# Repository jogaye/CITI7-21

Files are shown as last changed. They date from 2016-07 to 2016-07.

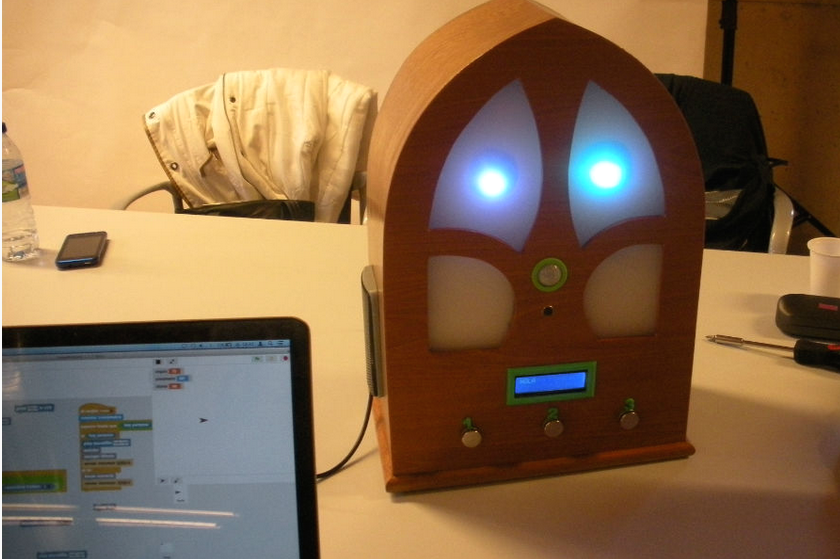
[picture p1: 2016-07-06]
Citi7-21.png

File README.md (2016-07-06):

# Citi7-21
Robot Nous Artesans

Projecte dels Nous Artesans del Citilab de Cornellà
A project of Citilab Cornellà New Artesans
http://nartesanos.citilab.eu/

Amb el suport del equip Edutec del Citilab 
With the support of Edutec Citilab team
http://edutec.citilab.eu

Robot que grava amb una tarja SD els suggeriments dels usuaris del Citilab  i que crida l'atenció per fomentar la participació.

Parla en 3 idiomes, es mou, té un sensor de presència, un display LCD, ulls amb LEDS RGB motoritzats i botons capacitius.

Està construït amb un Arduino Mega i programat amb Snap4Arduino. S'ha ampliat el Firmata per poder incorporar tots aquests elements al Snap4Arduino.

The Robot records in aSD card the feedback form Citilab users and draws his attention to encourage participation.

It speaks three languages, moves, has a presence sensor, a LCD display, two  RGBs LED motorized eyes and capacitive buttons.

It is built with an Arduino Mega and programmed with Snap4Arduino. Firmata has been expanded to incorporate all these elements to Snap4Arduino.

![Hello, I'm Citi7-21] (https://github.com/jogaye/Citi7-21/blob/master/Citi7-21.jpg)

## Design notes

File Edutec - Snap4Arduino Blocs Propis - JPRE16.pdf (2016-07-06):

### Edutec - Citilab

### Blocs propis amb Snap4Arduino

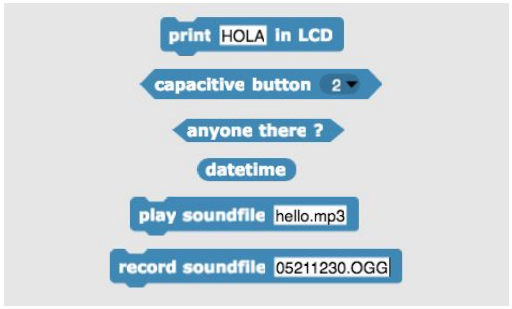
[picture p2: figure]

### Citilab Cornellà, 21 de maig 2016

Víctor Casado
José García
Joan Güell

# >> Citi 7 21

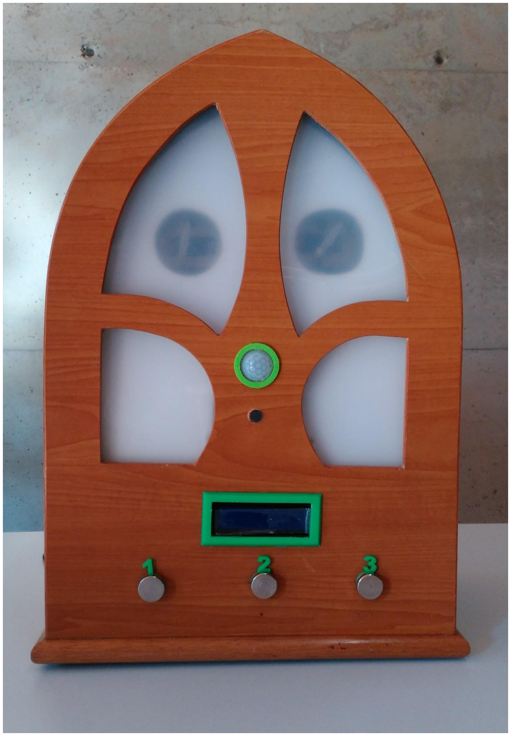
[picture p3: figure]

❏ | Robot en forma de “radio capilla” amb l’objectiu de gravar els suggeriments, propostes i també queixes dels usuaris del Citilab.
❏ | Parla en 3 idiomes, es mou, té un sensor de presència, un display LCD, ulls amb LEDS RGB motoritzats i botons capacitius.
❏ | Programat en Snap4Arduino

# >> Nous Artesans

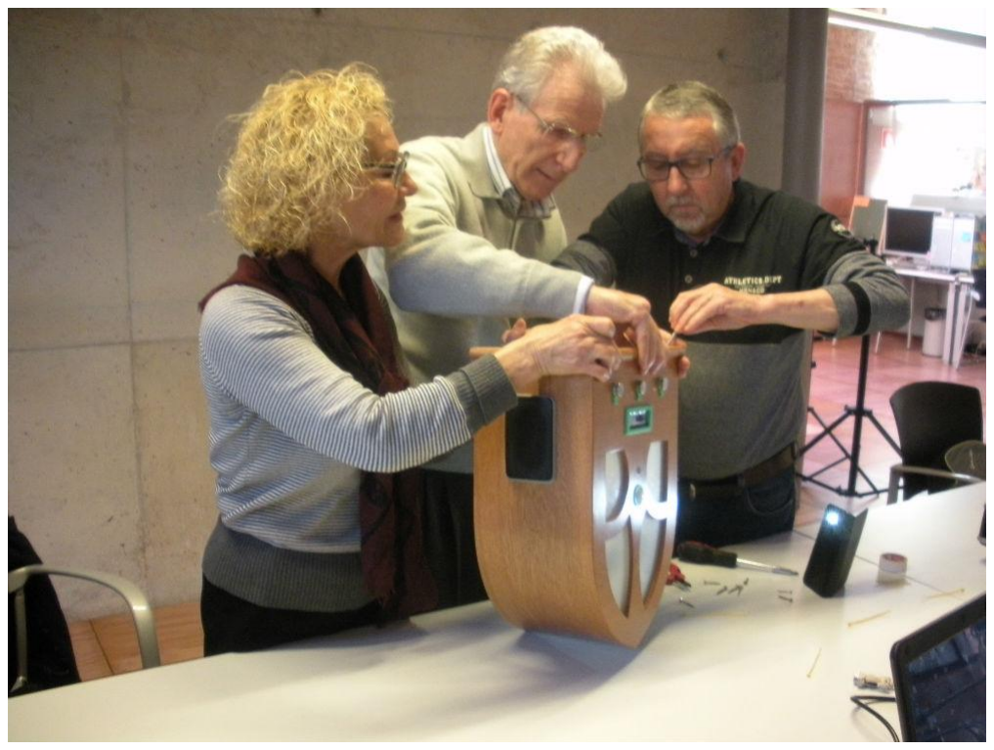
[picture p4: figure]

❏ | Projecte del Citilab on els ciutadans construeixen projectes propis, aprenent a mesura que els van fent. Combinen les seves habilitats amb la programació, l’electrònica i el 3D.
❏ | En el cas de Citi 7 21 es tracta d’un projecte bastant complexe pel que fa a l’electrónica i programació i hem tingut que crear peces específiques per Snap4Ardino.

### http://nartesanos.citilab.eu (http://nartesanos.citiab.eu)

## >> Blocs per dispositius específics

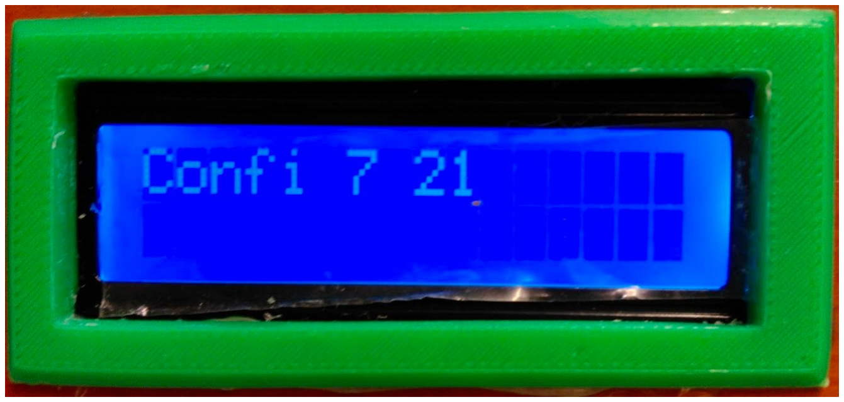
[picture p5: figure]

❏ | Comprovar el nou dispositiu en Arduino. Aïllar les llibreries necessàries pel seu funcionament.
❏ | Incorporar la llibreria al codi del StandarFirmata. Incloure les llibreries i afegir les comandes a void sysexCallback(byte command, byte argc, byte *argv)
❏ | Afegir el bloc corresponen al Snap4Arduino.

## >> LCD (Pantalla): Firmata

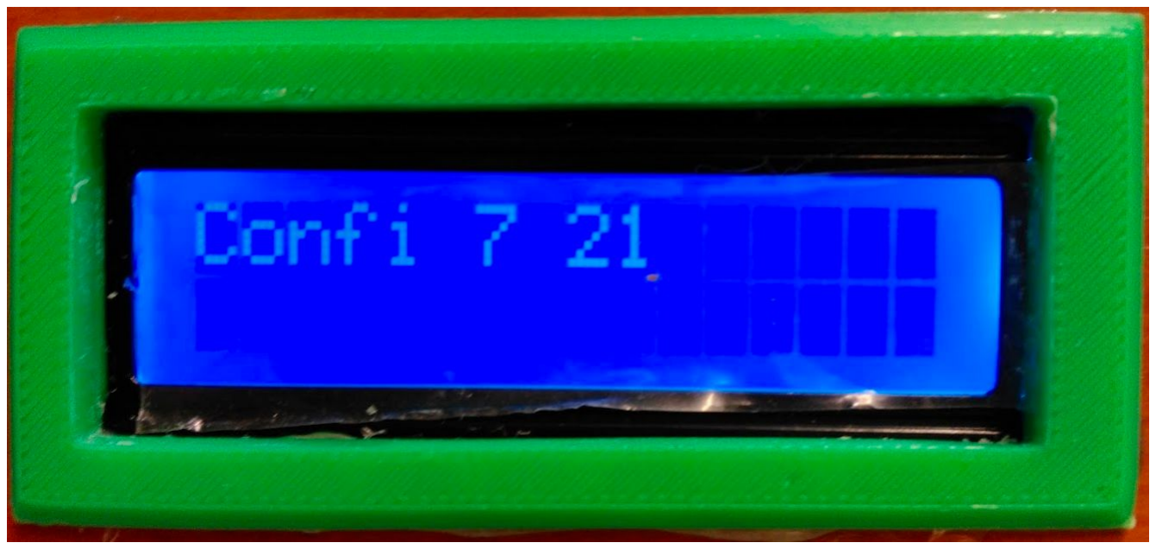
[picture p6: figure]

❏ // LCD 16x2 #include <LiquidCrystal.h> LiquidCrystal lcd(43, 41, 33, 35, 37, 39); …. void sysexCallback(byte command, byte argc, byte *argv) …. case 0x08: // Print for (int c = 0; c < argc; c++) { lcd.write(argv[c]); } case 0x09: // Clear lcd.clear(); case 0x0A: // Set Cursor lcd.setCursor(argv[0], argv[1]);

## >> LCD (Pantalla): Snap4Arduino

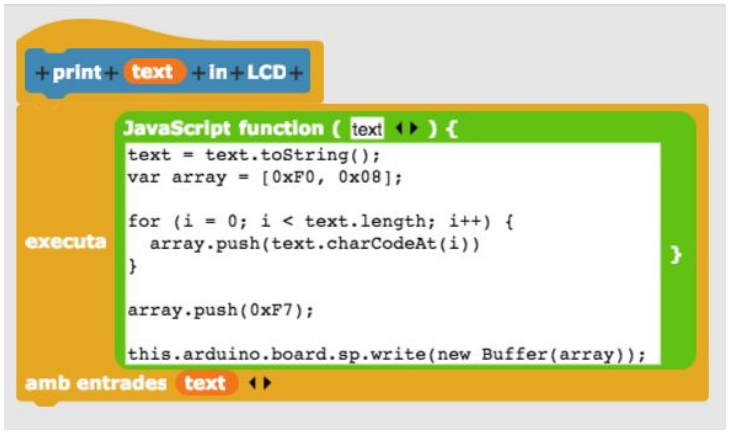
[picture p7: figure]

## >> LCD (Pantalla): Snap4Arduino

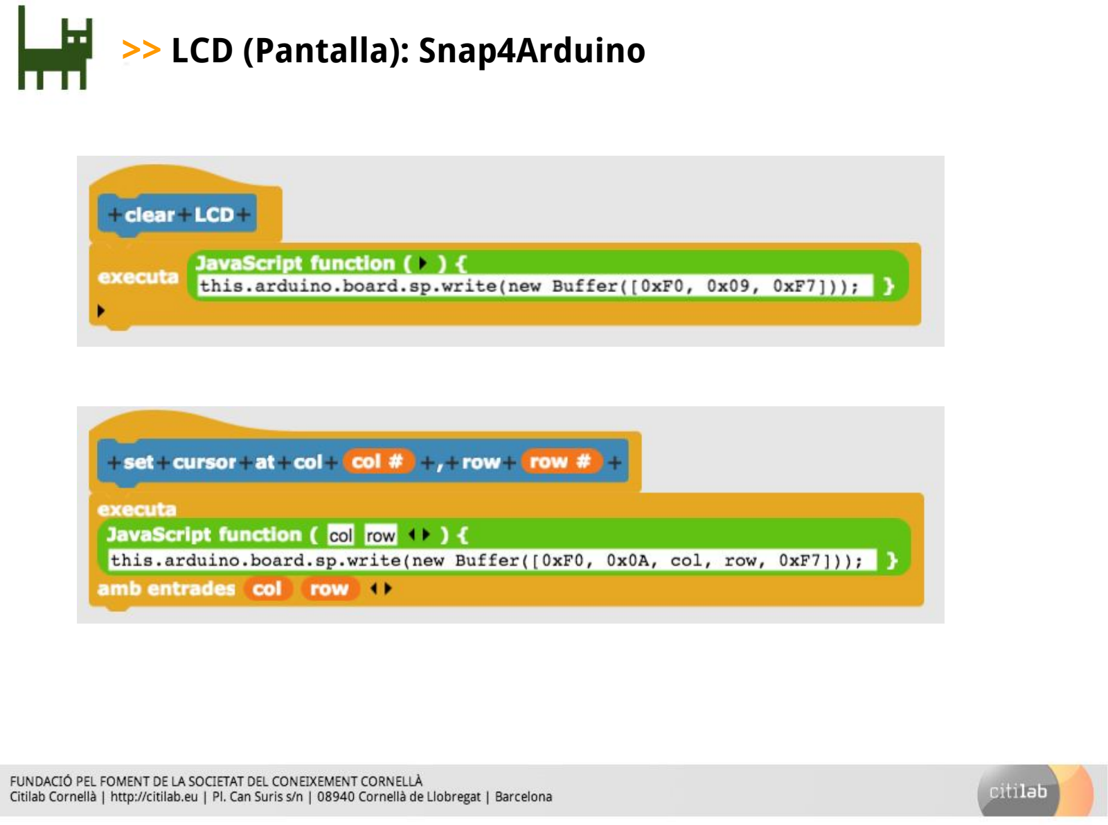
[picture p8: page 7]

## >> LCD (Pantalla): Firmata

❏ // LCD 16x2 #include <LiquidCrystal.h> LiquidCrystal lcd(43, 41, 33, 35, 37, 39); …. void sysexCallback(byte command, byte argc, byte *argv) …. case 0x08: // Print for (int c = 0; c < argc; c++) { lcd.write(argv[c]); } case 0x09: // Clear lcd.clear(); case 0x0A: // Set Cursor lcd.setCursor(argv[0], argv[1]);

## >> RTC (Rellotge temps real): Firmata

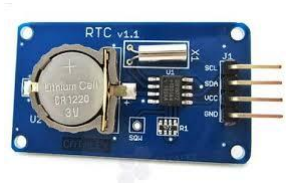
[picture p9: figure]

❏ | ///RTC Clock #include <Time.h> #include <DS1307RTC.h>
| …. void sysexCallback(byte command, byte argc, byte *argv) …. case 0x0F: // Clock; Serial.write(START_SYSEX); Serial.write(STRING_DATA); Serial.println(datetime()); Serial.write(END_SYSEX);
| …
| String datetime () { tmElements_t tm; RTC.read(tm); return twoDigits(tm.Month) + twoDigits(tm.Day) + twoDigits(tm.Hour) + twoDigits(tm.Minute); }

## >> RTC (Rellotge temps real): Snap4Arduino

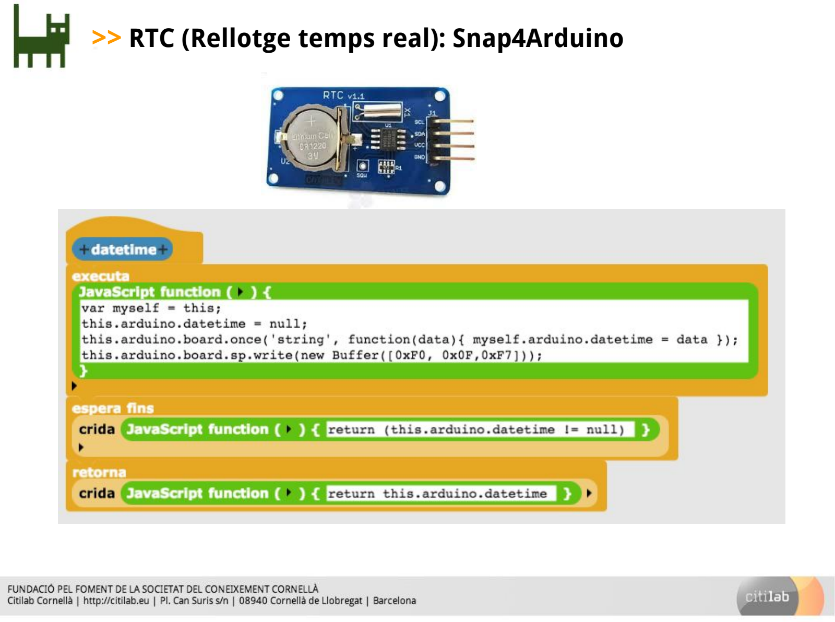
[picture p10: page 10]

## >> Blocs propis

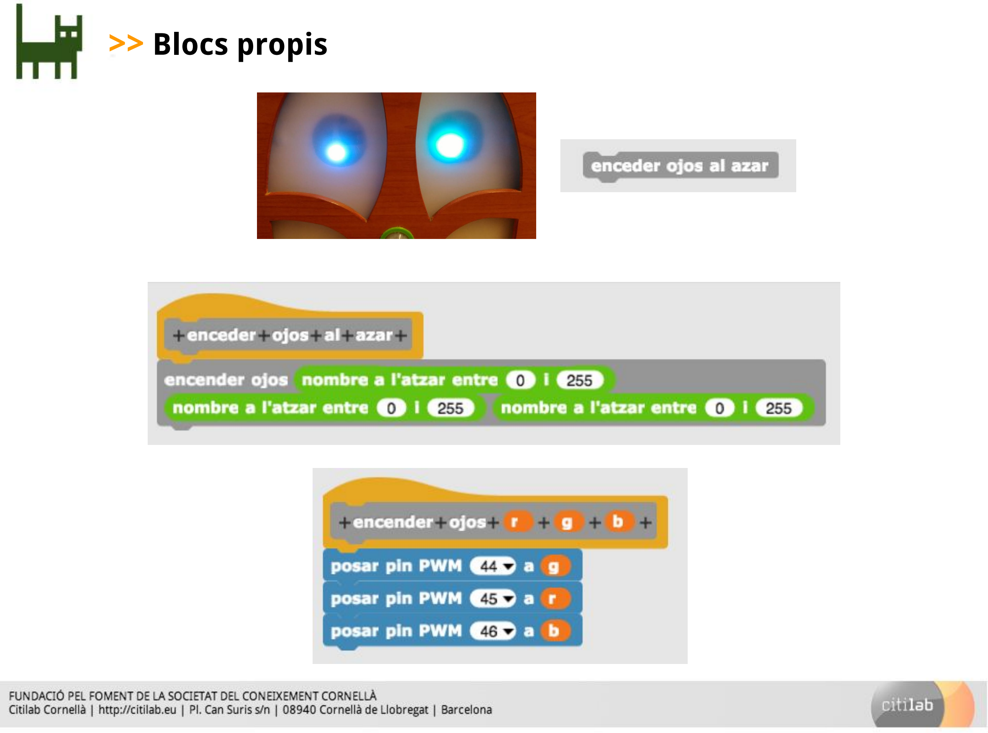
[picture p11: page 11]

## >> Programa final

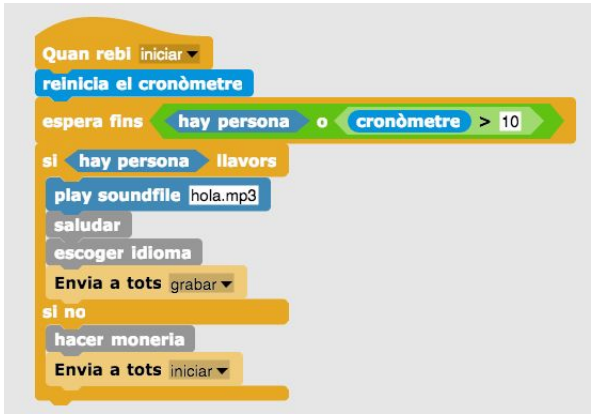
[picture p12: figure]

# >> Gràcies

# Preguntes ?

# >> Equip d’Edutec (Citilab)

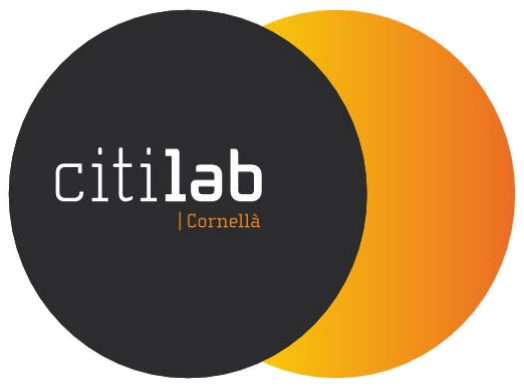
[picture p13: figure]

### http://edutec.citilab.eu http://s4a.cat http://www.citilab.eu

# Gràcies

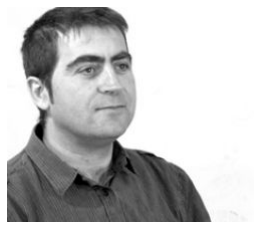
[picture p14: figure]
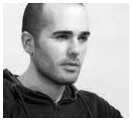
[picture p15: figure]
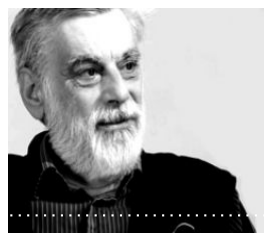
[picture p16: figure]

Victor Casado | José García | Joan Güell

### edutec@e-citilab.eu

Agraïments i reconeixents a Jordi Delgado i Bernat Romagosa

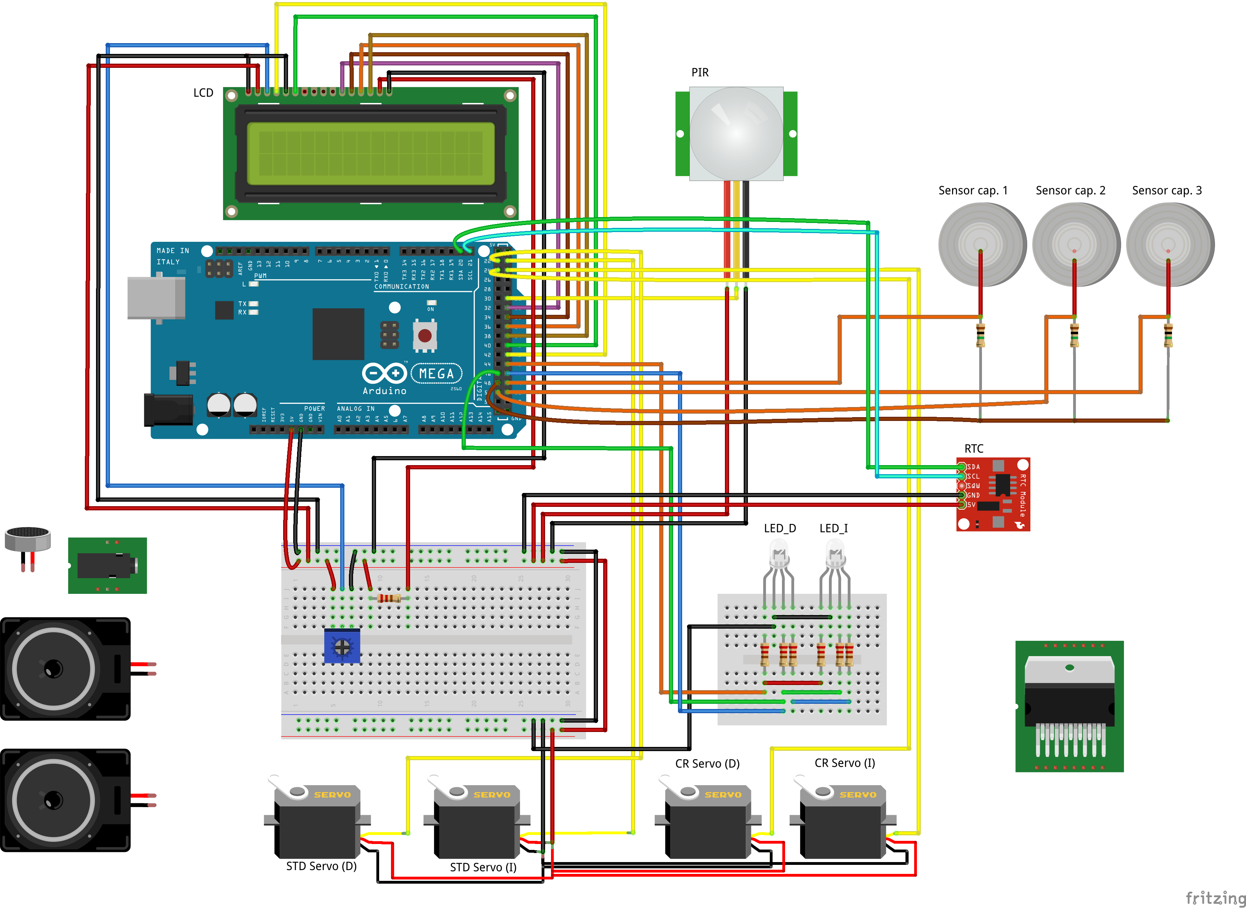
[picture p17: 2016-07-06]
Arduino/CITI721.png

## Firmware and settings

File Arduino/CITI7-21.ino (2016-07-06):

/*
   Firmata is a generic protocol for communicating with microcontrollers
   from software on a host computer. It is intended to work with
   any host computer software package.

   To download a host software package, please clink on the following link
   to open the download page in your default browser.

   http://firmata.org/wiki/Download
*/

/*
  Copyright (C) 2006-2008 Hans-Christoph Steiner.  All rights reserved.
  Copyright (C) 2010-2011 Paul Stoffregen.  All rights reserved.
  Copyright (C) 2009 Shigeru Kobayashi.  All rights reserved.
  Copyright (C) 2009-2011 Jeff Hoefs.  All rights reserved.

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
  See file LICENSE.txt for further informations on licensing terms.

  formatted using the GNU C formatting and indenting
*/

/*
   TODO: use Program Control to load stored profiles from EEPROM
*/

#include <Servo.h>
#include <Wire.h>
#include <Firmata.h>
// LCD 16x2
#include <LiquidCrystal.h>
// Capcaitive Sensors
#include <CapacitiveSensor.h>
// MP3 Shield
//include SPI, MP3 and SD libraries
#include <SPI.h>
#include <Adafruit_VS1053.h>
#include <SD.h>
//RTC Clock
#include <Time.h>
#include <DS1307RTC.h>

// MP3 Shield
#define SHIELD_RESET  -1      // VS1053 reset pin (unused!)
#define SHIELD_CS     7      // VS1053 chip select pin (output)
#define SHIELD_DCS    6      // VS1053 Data/command select pin (output)
// These are common pins between breakout and shield
#define CARDCS 4     // Card chip select pin
// DREQ should be an Int pin, see http://arduino.cc/en/Reference/attachInterrupt
#define DREQ 3       // VS1053 Data request, ideally an Interrupt pin

Adafruit_VS1053_FilePlayer musicPlayer = Adafruit_VS1053_FilePlayer(SHIELD_RESET, SHIELD_CS, SHIELD_DCS, DREQ, CARDCS);

File recording;  // the file we will save our recording to
#define RECBUFFSIZE 128  // 64 or 128 bytes.
uint8_t recording_buffer[RECBUFFSIZE];
char oggFilename[16];


// LCD 16x2
//LiquidCrystal lcd(8, 13, 9, 4, 5, 6, 7);

LiquidCrystal lcd(43, 41, 33, 35, 37, 39);

// Capcaitive Sensors
CapacitiveSensor   CS1 = CapacitiveSensor(48, 49);
CapacitiveSensor   CS2 = CapacitiveSensor(48, 50);
CapacitiveSensor   CS3 = CapacitiveSensor(48, 14); //52 no funciona!!



// move the following defines to Firmata.h?
#define I2C_WRITE B00000000
#define I2C_READ B00001000
#define I2C_READ_CONTINUOUSLY B00010000
#define I2C_STOP_READING B00011000
#define I2C_READ_WRITE_MODE_MASK B00011000
#define I2C_10BIT_ADDRESS_MODE_MASK B00100000

#define MAX_QUERIES 8
#define MINIMUM_SAMPLING_INTERVAL 10

#define REGISTER_NOT_SPECIFIED -1

/*==============================================================================
   GLOBAL VARIABLES
  ============================================================================*/

/* analog inputs */
int analogInputsToReport = 0; // bitwise array to store pin reporting

/* digital input ports */
byte reportPINs[TOTAL_PORTS];       // 1 = report this port, 0 = silence
byte previousPINs[TOTAL_PORTS];     // previous 8 bits sent

/* pins configuration */
byte pinConfig[TOTAL_PINS];         // configuration of every pin
byte portConfigInputs[TOTAL_PORTS]; // each bit: 1 = pin in INPUT, 0 = anything else
int pinState[TOTAL_PINS];           // any value that has been written

/* timer variables */
unsigned long currentMillis;        // store the current value from millis()
unsigned long previousMillis;       // for comparison with currentMillis
int samplingInterval = 99;          // how often to run the main loop (in ms)

/* i2c data */
struct i2c_device_info {
  byte addr;
  byte reg;
  byte bytes;
};

/* for i2c read continuous more */
i2c_device_info query[MAX_QUERIES];

byte i2cRxData[32];
boolean isI2CEnabled = false;
signed char queryIndex = -1;
unsigned int i2cReadDelayTime = 0;  // default delay time between i2c read request and Wire.requestFrom()

Servo servos[MAX_SERVOS];
/*==============================================================================
   FUNCTIONS
  ============================================================================*/

void readAndReportData(byte address, int theRegister, byte numBytes) {
  // allow I2C requests that don't require a register read
  // for example, some devices using an interrupt pin to signify new data available
  // do not always require the register read so upon interrupt you call Wire.requestFrom()
  if (theRegister != REGISTER_NOT_SPECIFIED) {
    Wire.beginTransmission(address);
#if ARDUINO >= 100
    Wire.write((byte)theRegister);
#else
    Wire.send((byte)theRegister);
#endif
    Wire.endTransmission();
    delayMicroseconds(i2cReadDelayTime);  // delay is necessary for some devices such as WiiNunchuck
  } else {
    theRegister = 0;  // fill the register with a dummy value
  }

  Wire.requestFrom(address, numBytes);  // all bytes are returned in requestFrom

  // check to be sure correct number of bytes were returned by slave
  if (numBytes == Wire.available()) {
    i2cRxData[0] = address;
    i2cRxData[1] = theRegister;
    for (int i = 0; i < numBytes; i++) {
#if ARDUINO >= 100
      i2cRxData[2 + i] = Wire.read();
#else
      i2cRxData[2 + i] = Wire.receive();
#endif
    }
  }
  else {
    if (numBytes > Wire.available()) {
      Firmata.sendString("I2C Read Error: Too many bytes received");
    } else {
      Firmata.sendString("I2C Read Error: Too few bytes received");
    }
  }

  // send slave address, register and received bytes
  Firmata.sendSysex(SYSEX_I2C_REPLY, numBytes + 2, i2cRxData);
}

void outputPort(byte portNumber, byte portValue, byte forceSend)
{
  // pins not configured as INPUT are cleared to zeros
  portValue = portValue & portConfigInputs[portNumber];
  // only send if the value is different than previously sent
  if (forceSend || previousPINs[portNumber] != portValue) {
    Firmata.sendDigitalPort(portNumber, portValue);
    previousPINs[portNumber] = portValue;
  }
}

/* -----------------------------------------------------------------------------
   check all the active digital inputs for change of state, then add any events
   to the Serial output queue using Serial.print() */
void checkDigitalInputs(void)
{
  /* Using non-looping code allows constants to be given to readPort().
     The compiler will apply substantial optimizations if the inputs
     to readPort() are compile-time constants. */
  if (TOTAL_PORTS > 0 && reportPINs[0]) outputPort(0, readPort(0, portConfigInputs[0]), false);
  if (TOTAL_PORTS > 1 && reportPINs[1]) outputPort(1, readPort(1, portConfigInputs[1]), false);
  if (TOTAL_PORTS > 2 && reportPINs[2]) outputPort(2, readPort(2, portConfigInputs[2]), false);
  if (TOTAL_PORTS > 3 && reportPINs[3]) outputPort(3, readPort(3, portConfigInputs[3]), false);
  if (TOTAL_PORTS > 4 && reportPINs[4]) outputPort(4, readPort(4, portConfigInputs[4]), false);
  if (TOTAL_PORTS > 5 && reportPINs[5]) outputPort(5, readPort(5, portConfigInputs[5]), false);
  if (TOTAL_PORTS > 6 && reportPINs[6]) outputPort(6, readPort(6, portConfigInputs[6]), false);
  if (TOTAL_PORTS > 7 && reportPINs[7]) outputPort(7, readPort(7, portConfigInputs[7]), false);
  if (TOTAL_PORTS > 8 && reportPINs[8]) outputPort(8, readPort(8, portConfigInputs[8]), false);
  if (TOTAL_PORTS > 9 && reportPINs[9]) outputPort(9, readPort(9, portConfigInputs[9]), false);
  if (TOTAL_PORTS > 10 && reportPINs[10]) outputPort(10, readPort(10, portConfigInputs[10]), false);
  if (TOTAL_PORTS > 11 && reportPINs[11]) outputPort(11, readPort(11, portConfigInputs[11]), false);
  if (TOTAL_PORTS > 12 && reportPINs[12]) outputPort(12, readPort(12, portConfigInputs[12]), false);
  if (TOTAL_PORTS > 13 && reportPINs[13]) outputPort(13, readPort(13, portConfigInputs[13]), false);
  if (TOTAL_PORTS > 14 && reportPINs[14]) outputPort(14, readPort(14, portConfigInputs[14]), false);
  if (TOTAL_PORTS > 15 && reportPINs[15]) outputPort(15, readPort(15, portConfigInputs[15]), false);
}

// -----------------------------------------------------------------------------
/* sets the pin mode to the correct state and sets the relevant bits in the
   two bit-arrays that track Digital I/O and PWM status
*/
void setPinModeCallback(byte pin, int mode)
{
  if (pinConfig[pin] == I2C && isI2CEnabled && mode != I2C) {
    // disable i2c so pins can be used for other functions
    // the following if statements should reconfigure the pins properly
    disableI2CPins();
  }
  if (IS_PIN_SERVO(pin) && mode != SERVO && servos[PIN_TO_SERVO(pin)].attached()) {
    servos[PIN_TO_SERVO(pin)].detach();
  }
  if (IS_PIN_ANALOG(pin)) {
    reportAnalogCallback(PIN_TO_ANALOG(pin), mode == ANALOG ? 1 : 0); // turn on/off reporting
  }
  if (IS_PIN_DIGITAL(pin)) {
    if (mode == INPUT) {
      portConfigInputs[pin / 8] |= (1 << (pin & 7));
    } else {
      portConfigInputs[pin / 8] &= ~(1 << (pin & 7));
    }
  }
  pinState[pin] = 0;
  switch (mode) {
    case ANALOG:
      if (IS_PIN_ANALOG(pin)) {
        if (IS_PIN_DIGITAL(pin)) {
          pinMode(PIN_TO_DIGITAL(pin), INPUT); // disable output driver
          digitalWrite(PIN_TO_DIGITAL(pin), LOW); // disable internal pull-ups
        }
        pinConfig[pin] = ANALOG;
      }
      break;
    case INPUT:
      if (IS_PIN_DIGITAL(pin)) {
        pinMode(PIN_TO_DIGITAL(pin), INPUT); // disable output driver
        digitalWrite(PIN_TO_DIGITAL(pin), LOW); // disable internal pull-ups
        pinConfig[pin] = INPUT;
      }
      break;
    case OUTPUT:
      if (IS_PIN_DIGITAL(pin)) {
        digitalWrite(PIN_TO_DIGITAL(pin), LOW); // disable PWM
        pinMode(PIN_TO_DIGITAL(pin), OUTPUT);
        pinConfig[pin] = OUTPUT;
      }
      break;
    case PWM:
      if (IS_PIN_PWM(pin)) {
        pinMode(PIN_TO_PWM(pin), OUTPUT);
        analogWrite(PIN_TO_PWM(pin), 0);
        pinConfig[pin] = PWM;
      }
      break;
    case SERVO:
      if (IS_PIN_SERVO(pin)) {
        pinConfig[pin] = SERVO;
        if (!servos[PIN_TO_SERVO(pin)].attached()) {
          servos[PIN_TO_SERVO(pin)].attach(PIN_TO_DIGITAL(pin));
        }
      }
      break;
    case I2C:
      if (IS_PIN_I2C(pin)) {
        // mark the pin as i2c
        // the user must call I2C_CONFIG to enable I2C for a device
        pinConfig[pin] = I2C;
      }
      break;
    default:
      Firmata.sendString("Unknown pin mode"); // TODO: put error msgs in EEPROM
  }
  // TODO: save status to EEPROM here, if changed
}

void analogWriteCallback(byte pin, int value)
{
  if (pin < TOTAL_PINS) {
    switch (pinConfig[pin]) {
      case SERVO:
        if (IS_PIN_SERVO(pin))
          servos[PIN_TO_SERVO(pin)].write(value);
        pinState[pin] = value;
        break;
      case PWM:
        if (IS_PIN_PWM(pin))
          analogWrite(PIN_TO_PWM(pin), value);
        pinState[pin] = value;
        break;
    }
  }
}

void digitalWriteCallback(byte port, int value)
{
  byte pin, lastPin, mask = 1, pinWriteMask = 0;

  if (port < TOTAL_PORTS) {
    // create a mask of the pins on this port that are writable.
    lastPin = port * 8 + 8;
    if (lastPin > TOTAL_PINS) lastPin = TOTAL_PINS;
    for (pin = port * 8; pin < lastPin; pin++) {
      // do not disturb non-digital pins (eg, Rx & Tx)
      if (IS_PIN_DIGITAL(pin)) {
        // only write to OUTPUT and INPUT (enables pullup)
        // do not touch pins in PWM, ANALOG, SERVO or other modes
        if (pinConfig[pin] == OUTPUT || pinConfig[pin] == INPUT) {
          pinWriteMask |= mask;
          pinState[pin] = ((byte)value & mask) ? 1 : 0;
        }
      }
      mask = mask << 1;
    }
    writePort(port, (byte)value, pinWriteMask);
  }
}


// -----------------------------------------------------------------------------
/* sets bits in a bit array (int) to toggle the reporting of the analogIns
*/
//void FirmataClass::setAnalogPinReporting(byte pin, byte state) {
//}
void reportAnalogCallback(byte analogPin, int value)
{
  if (analogPin < TOTAL_ANALOG_PINS) {
    if (value == 0) {
      analogInputsToReport = analogInputsToReport & ~ (1 << analogPin);
    } else {
      analogInputsToReport = analogInputsToReport | (1 << analogPin);
    }
  }
  // TODO: save status to EEPROM here, if changed
}

void reportDigitalCallback(byte port, int value)
{
  if (port < TOTAL_PORTS) {
    reportPINs[port] = (byte)value;
  }
  // do not disable analog reporting on these 8 pins, to allow some
  // pins used for digital, others analog.  Instead, allow both types
  // of reporting to be enabled, but check if the pin is configured
  // as analog when sampling the analog inputs.  Likewise, while
  // scanning digital pins, portConfigInputs will mask off values from any
  // pins configured as analog
}

// MP3 Shield
int isRecording = false;
unsigned long start_time;
int record_time = 20; ///seconds

uint16_t saveRecordedData(boolean isrecord) {
  uint16_t written = 0;

  // read how many words are waiting for us
  uint16_t wordswaiting = musicPlayer.recordedWordsWaiting();

  // try to process 256 words (512 bytes) at a time, for best speed
  while (wordswaiting > 256) {
    //Serial.print("Waiting: "); Serial.println(wordswaiting);
    // for example 128 bytes x 4 loops = 512 bytes
    for (int x = 0; x < 512 / RECBUFFSIZE; x++) {
      // fill the buffer!
      for (uint16_t addr = 0; addr < RECBUFFSIZE; addr += 2) {
        uint16_t t = musicPlayer.recordedReadWord();
        //Serial.println(t, HEX);
        recording_buffer[addr] = t >> 8;
        recording_buffer[addr + 1] = t;
      }
      if (! recording.write(recording_buffer, RECBUFFSIZE)) {
        Serial.print("Couldn't write"); Serial.println(RECBUFFSIZE);
        //while (1);
      }
    }
    // flush 512 bytes at a time
    recording.flush();
    written += 256;
    wordswaiting -= 256;
  }

  wordswaiting = musicPlayer.recordedWordsWaiting();
  if (!isrecord) {
    //>Serial.print(wordswaiting); Serial.println(" remaining");
    // wrapping up the recording!
    uint16_t addr = 0;
    for (int x = 0; x < wordswaiting - 1; x++) {
      // fill the buffer!
      uint16_t t = musicPlayer.recordedReadWord();
      recording_buffer[addr] = t >> 8;
      recording_buffer[addr + 1] = t;
      if (addr > RECBUFFSIZE) {
        if (! recording.write(recording_buffer, RECBUFFSIZE)) {
          Serial.println("Couldn't write!");
          //while (1);
        }
        recording.flush();
        addr = 0;
      }
    }
    if (addr != 0) {
      if (!recording.write(recording_buffer, addr)) {
        Serial.println("Couldn't write!");
        //while (1);
      }
      written += addr;
    }
    musicPlayer.sciRead(VS1053_SCI_AICTRL3);
    if (! (musicPlayer.sciRead(VS1053_SCI_AICTRL3) & _BV(2))) {
      recording.write(musicPlayer.recordedReadWord() & 0xFF);
      written++;
    }
    recording.flush();
  }

  return written;
}


void beginRecording()
{
  start_time = millis();
  musicPlayer.setVolume(100, 100);
  if (!isRecording) {
    isRecording = true;
    // load plugin from SD card! We'll use mono 44.1KHz, high quality
    if (! musicPlayer.prepareRecordOgg("v44k1q05.img")) {
      lcd.write("Couldn't load plugin!");
    }
    //>Serial.println(start_time);
    //>Serial.println("Begin recording");
    start_time = millis();
    //SD.remove("CITI721.OGG");
    SD.remove(oggFilename);
    delay(100);
    //recording = SD.open("CITI721.OGG", FILE_WRITE);
    recording = SD.open(oggFilename, FILE_WRITE);
    delay(100);
    if (recording) {
      //>Serial.println("opened");
      lcd.clear();
      lcd.print("Recording...");
      musicPlayer.startRecordOgg(false); // use microphone (for linein, pass in 'false')
    };
  };
}

void endRecording()
{
  if (isRecording) {
    //>Serial.println("End recording");
    musicPlayer.stopRecordOgg();
    isRecording = false;
    // flush all the data!
    saveRecordedData(isRecording);
    // close it up
    recording.close();
    delay(1000);
    lcd.print("End");
  }
}


//RTC Clock

String twoDigits(int num) {
  if (num < 10)
    return ("0" + String(num));
  else
    return (String(num));
}

String datetime ()  {
  tmElements_t tm;
  RTC.read(tm);
  return twoDigits(tm.Month) + twoDigits(tm.Day) + twoDigits(tm.Hour) + twoDigits(tm.Minute);
}

/*==============================================================================
   SYSEX-BASED commands
  ============================================================================*/
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
void loop() {

  /*
    if (Serial.available()) {
      char c = Serial.read();
      if (c == 'r') {
        beginRecording();
      }

      if (c == 'p') {
        Serial.println("playing...");
         musicPlayer.setVolume(10,10);
         musicPlayer.sineTest(0x44, 500);
        musicPlayer.startPlayingFile("CITI721.OGG");

      }

    }

  */


  if (isRecording)
    saveRecordedData(isRecording);

  if (isRecording && (millis() > (start_time + (record_time * 1000))))
  {
    endRecording();
    Serial.println(millis());
  }


  /* DIGITALREAD - as fast as possible, check for changes and output them to the
     FTDI buffer using Serial.print()  */
  checkDigitalInputs();

  /* STREAMREAD - processing incoming messagse as soon as possible, while still
     checking digital inputs.  */
  while (Firmata.available())
    Firmata.processInput();


  delay(10);
}

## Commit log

2016-07-06 I’am Citi7-21
    [CITI721.fzz]
2016-07-06 I’m Citi7-21
2016-07-13 Examples of CapcitiveSensors and DHT11 sensors (thanks to Joan & Josep!)
2016-07-19 Support for BYJ48 stepper
